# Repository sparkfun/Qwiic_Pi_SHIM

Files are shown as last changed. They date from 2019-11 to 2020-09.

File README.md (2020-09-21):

SparkFun Qwiic SHIM for Raspberry Pi
========================================

SparkFun Qwiic SHIM for Raspberry Pi

[*SparkFun Qwiic SHIM for Raspberry Pi (15794)*](https://www.sparkfun.com/products/15794)

A small breakout board to add a qwiic connector to your Raspberry Pi 40pin header. SHIM (Shove Hardware In the Middle).

Repository Contents
-------------------

* **/Hardware** - Eagle design files (.brd, .sch)

Documentation
--------------
* **[Hookup Guide](https://learn.sparkfun.com/tutorials/qwiic-shim-for-raspberry-pi-hookup-guide)** - Basic hookup guide for the SparkFun Qwiic SHIM for Raspberry Pi. 

License Information
-------------------

This product is _**open source**_! 

Please review the LICENSE.md file for license information. 

If you have any questions or concerns on licensing, please contact technical support on our [SparkFun forums](https://forum.sparkfun.com/viewforum.php?f=152).

Distributed as-is; no warranty is given.

- Your friends at SparkFun.

_<COLLABORATION CREDIT>_

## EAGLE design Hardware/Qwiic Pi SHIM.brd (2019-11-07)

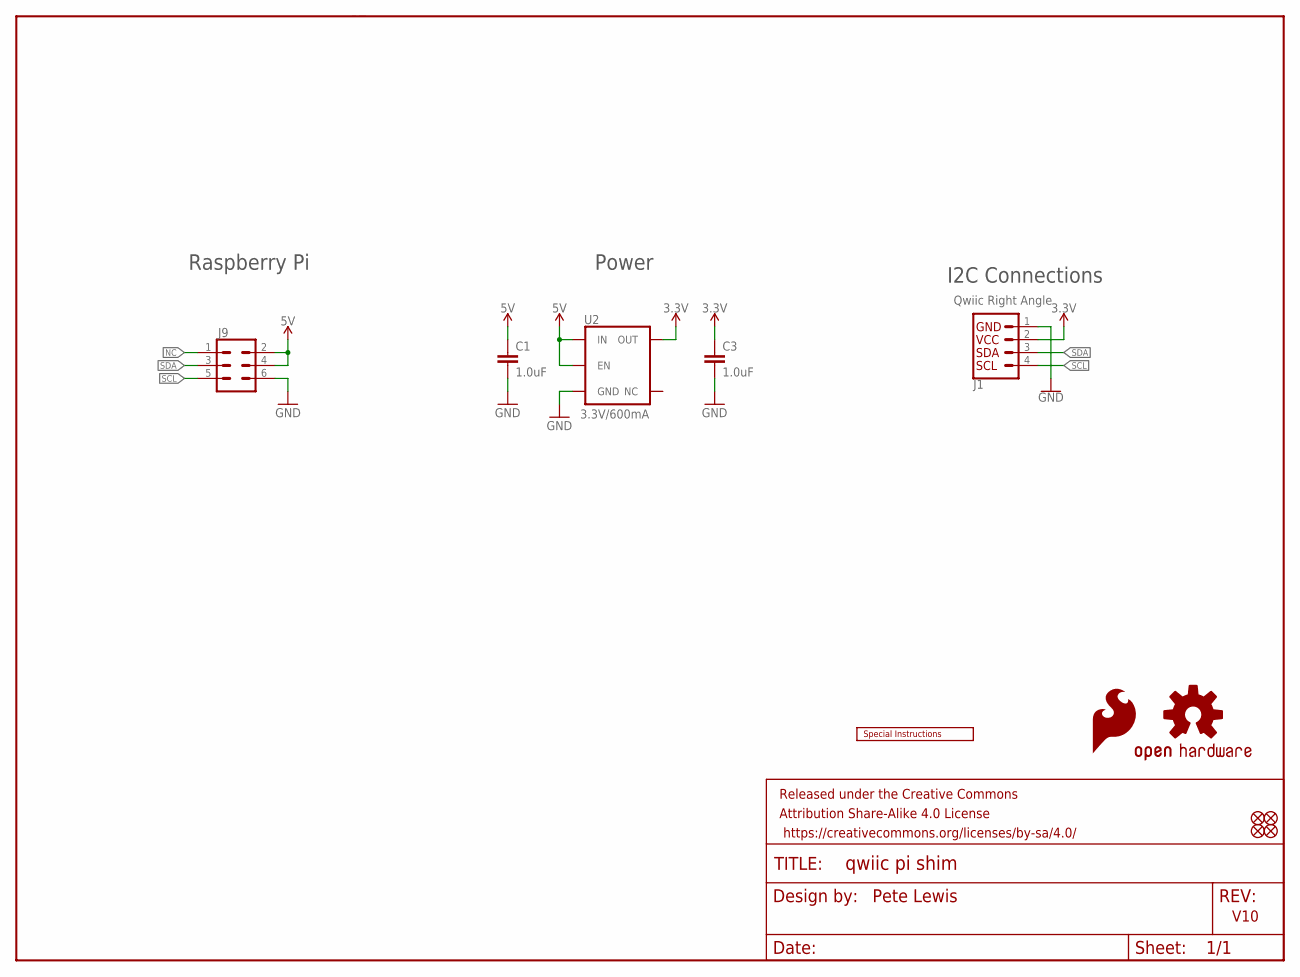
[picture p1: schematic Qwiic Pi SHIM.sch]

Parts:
C1, C3: 1.0uF; 0603
FD1, FD2, FD3, FD4: FIDUCIALUFIDUCIAL; FIDUCIAL-MICRO
FRAME1: FRAME-LETTER; CREATIVE_COMMONS
J1: Qwiic Right Angle; 1X04_1MM_RA
J9: SPARKFUN-CONNECTORS_CONN_03X2SINGLE_SLOT-4MILS; SPARKFUN-CONNECTORS_2X3-NS_PISHIM_LOCKING_SLOTS-4MILS
LOGO1: OSHW-LOGOMINI; OSHW-LOGO-MINI
U2: 3.3V/600mA; SOT23-5
U$1: SFE_LOGO_FLAME.1_INCH; SFE_LOGO_FLAME_.1
U$4: SPECIAL_INSTRUCTIONS-ORDERING; ORDERING_INSTRUCTIONS

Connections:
3.3V: C3.1, J1.2, U2.5 (OUT)
5V: C1.1, J9.2, J9.4, U2.1 (IN), U2.3 (EN)
GND: C1.2, C3.2, J1.1, J9.6, U2.2 (GND)
NC: J9.1
SCL: J1.4, J9.5
SDA: J1.3, J9.3

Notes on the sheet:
Pete Lewis
Raspberry Pi
V10
I2C Connections
Power

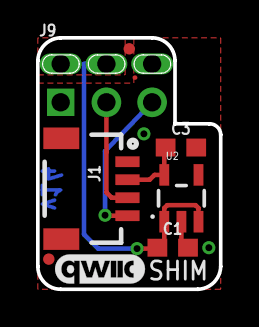
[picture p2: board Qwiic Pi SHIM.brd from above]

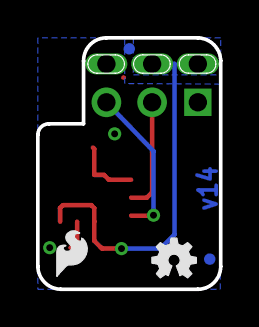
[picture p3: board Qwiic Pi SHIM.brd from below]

Board: 2 copper layers, 10.2 x 14.0 mm, 14 parts (4 on the bottom side), 5 nets.

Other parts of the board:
U$3: QWIIC_5MM

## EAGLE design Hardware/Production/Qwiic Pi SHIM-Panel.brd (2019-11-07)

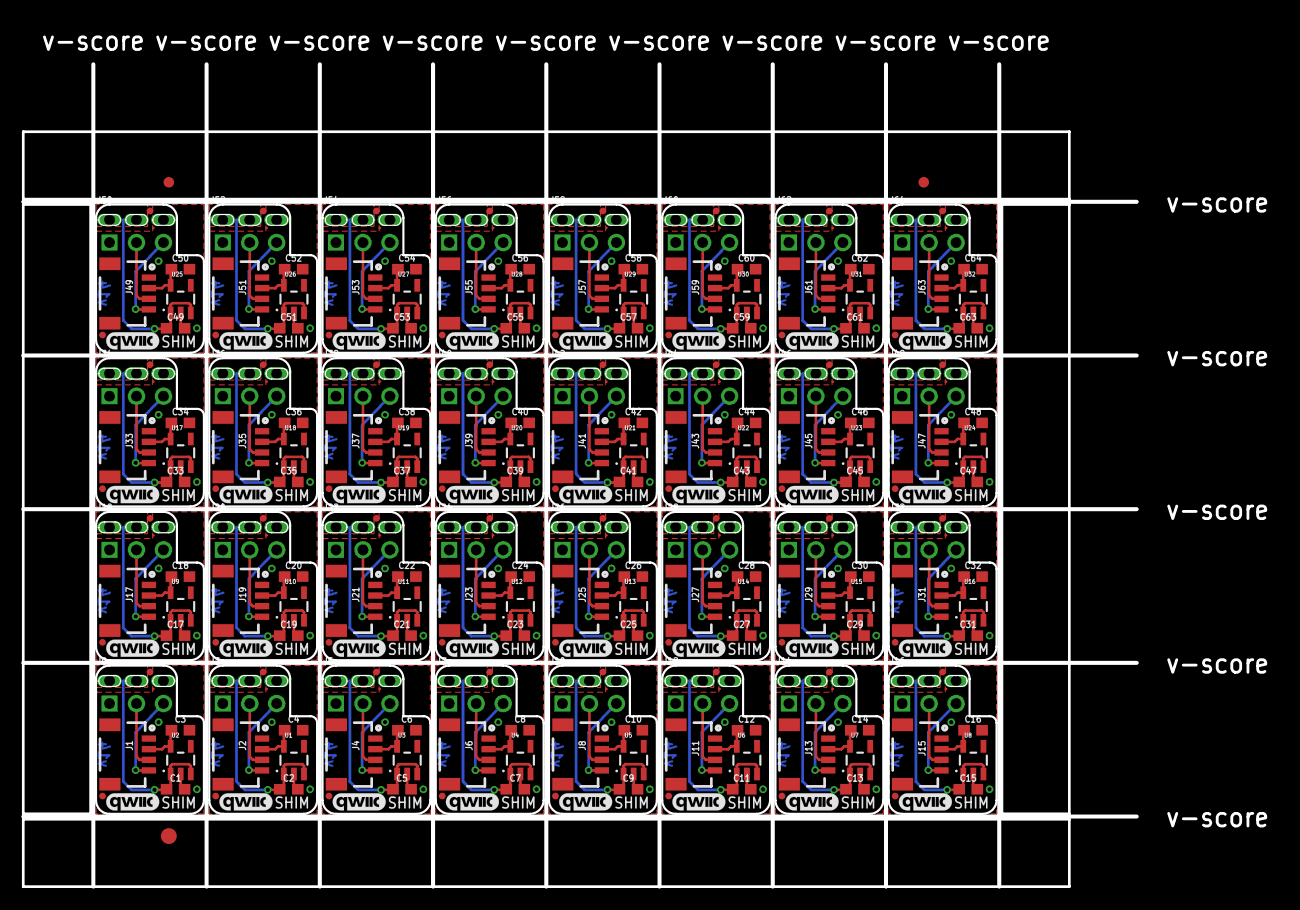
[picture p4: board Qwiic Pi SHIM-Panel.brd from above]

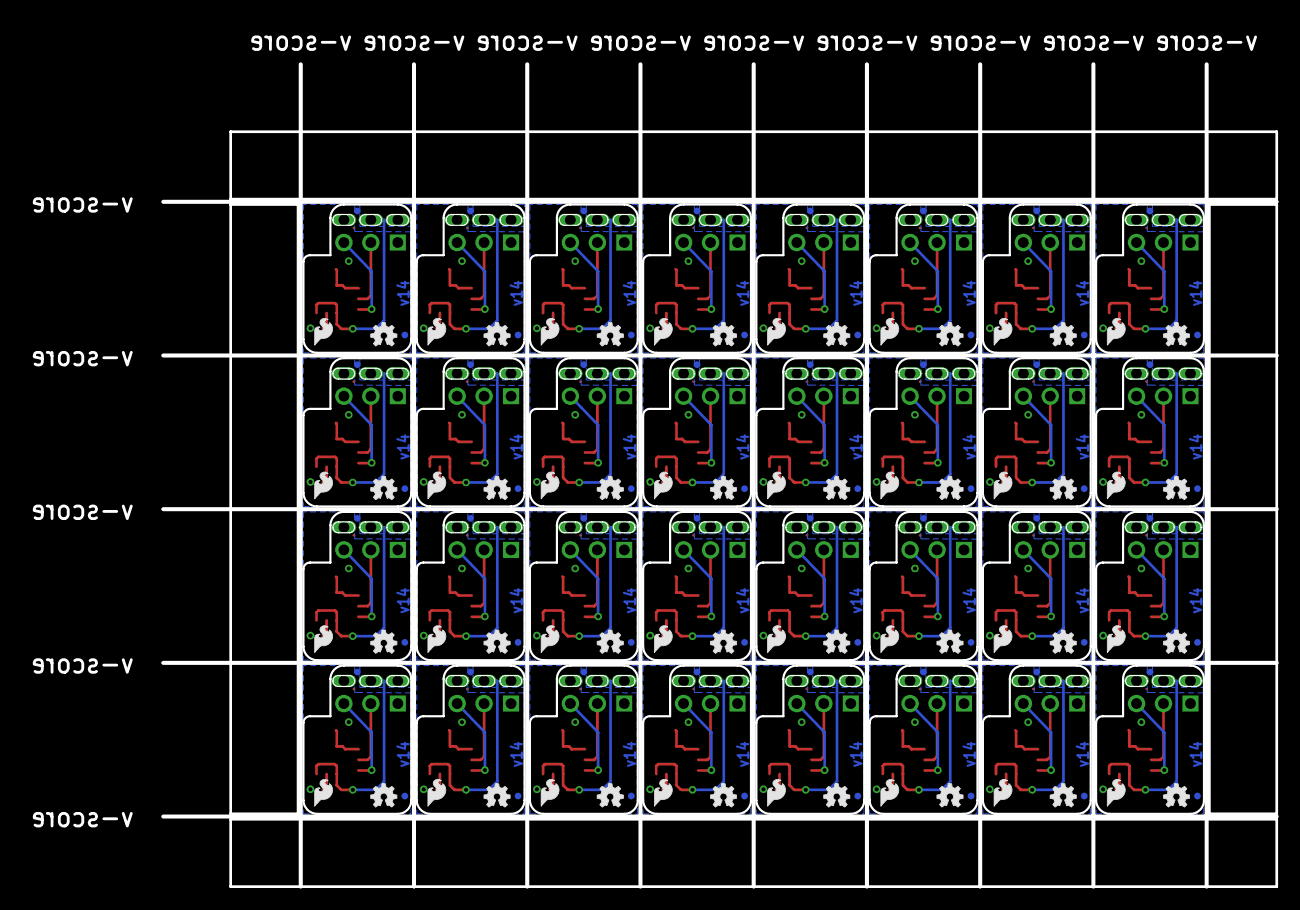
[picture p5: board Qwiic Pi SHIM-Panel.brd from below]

Board: 2 copper layers, 104.9 x 77.5 mm, 387 parts (128 on the bottom side), 160 nets.

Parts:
C1, C2, C3, C4, C5, C6, C7, C8, C9, C10, C11, C12, C13, C14, C15, C16, C17, C18, C19, C20, C21, C22, C23, C24, C25, C26, C27, C28, C29, C30, C31, C32, C33, C34, C35, C36, C37, C38, C39, C40, C41, C42, C43, C44, C45, C46, C47, C48, C49, C50, C51, C52, C53, C54, C55, C56, C57, C58, C59, C60, C61, C62, C63, C64: 1.0uF; 0603
E$1, E$2: FIDUCIAL-1X2
E$3: FIDUCIAL-1.5X3
FD1, FD2, FD3, FD4, FD5, FD6, FD7, FD8, FD9, FD10, FD11, FD12, FD13, FD14, FD15, FD16, FD17, FD18, FD19, FD20, FD21, FD22, FD23, FD24, FD25, FD26, FD27, FD28, FD29, FD30, FD31, FD32, FD33, FD34, FD35, FD36, FD37, FD38, FD39, FD40, FD41, FD42, FD43, FD44, FD45, FD46, FD47, FD48, FD49, FD50, FD51, FD52, FD53, FD54, FD55, FD56, FD57, FD58, FD59, FD60, FD61, FD62, FD63, FD64, FD65, FD66, FD67, FD68, FD69, FD70, FD71, FD72, FD73, FD74, FD75, FD76, FD77, FD78, FD79, FD80, FD81, FD82, FD83, FD84, FD85, FD86, FD87, FD88, FD89, FD90, FD91, FD92, FD93, FD94, FD95, FD96, FD97, FD98, FD99, FD100, FD101, FD102, FD103, FD104, FD105, FD106, FD107, FD108, FD109, FD110, FD111, FD112, FD113, FD114, FD115, FD116, FD117, FD118, FD119, FD120, FD121, FD122, FD123, FD124, FD125, FD126, FD127, FD128: FIDUCIALUFIDUCIAL; FIDUCIAL-MICRO
J1, J2, J4, J6, J8, J11, J13, J15, J17, J19, J21, J23, J25, J27, J29, J31, J33, J35, J37, J39, J41, J43, J45, J47, J49, J51, J53, J55, J57, J59, J61, J63: Qwiic Right Angle; 1X04_1MM_RA
J3, J5, J7, J9, J10, J12, J14, J16, J18, J20, J22, J24, J26, J28, J30, J32, J34, J36, J38, J40, J42, J44, J46, J48, J50, J52, J54, J56, J58, J60, J62, J64: SPARKFUN-CONNECTORS_2X3-NS_PISHIM_LOCKING_SLOTS-4MILS
LOGO1, LOGO2, LOGO3, LOGO4, LOGO5, LOGO6, LOGO7, LOGO8, LOGO9, LOGO10, LOGO11, LOGO12, LOGO13, LOGO14, LOGO15, LOGO16, LOGO17, LOGO18, LOGO19, LOGO20, LOGO21, LOGO22, LOGO23, LOGO24, LOGO25, LOGO26, LOGO27, LOGO28, LOGO29, LOGO30, LOGO31, LOGO32: OSHW-LOGOMINI; OSHW-LOGO-MINI
U1, U2, U3, U4, U5, U6, U7, U8, U9, U10, U11, U12, U13, U14, U15, U16, U17, U18, U19, U20, U21, U22, U23, U24, U25, U26, U27, U28, U29, U30, U31, U32: 3.3V/600mA; SOT23-5
U$1, U$2, U$5, U$7, U$9, U$11, U$13, U$15, U$17, U$19, U$21, U$23, U$25, U$27, U$29, U$31, U$33, U$35, U$37, U$39, U$41, U$43, U$45, U$47, U$49, U$51, U$53, U$55, U$57, U$59, U$61, U$63: SFE_LOGO_FLAME.1_INCH; SFE_LOGO_FLAME_.1
U$3, U$4, U$6, U$8, U$10, U$12, U$14, U$16, U$18, U$20, U$22, U$24, U$26, U$28, U$30, U$32, U$34, U$36, U$38, U$40, U$42, U$44, U$46, U$48, U$50, U$52, U$54, U$56, U$58, U$60, U$62, U$64: QWIIC_5MM

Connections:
3.3V: C3.1, J1.2, U2.5
3.3V1: C4.1, J2.2, U1.5
3.3V2: C6.1, J4.2, U3.5
3.3V3: C8.1, J6.2, U4.5
3.3V4: C10.1, J8.2, U5.5
3.3V5: C12.1, J11.2, U6.5
3.3V6: C14.1, J13.2, U7.5
3.3V7: C16.1, J15.2, U8.5
3.3V8: C18.1, J17.2, U9.5
3.3V9: C20.1, J19.2, U10.5
3.3V10: C22.1, J21.2, U11.5
3.3V11: C24.1, J23.2, U12.5
3.3V12: C26.1, J25.2, U13.5
3.3V13: C28.1, J27.2, U14.5
3.3V14: C30.1, J29.2, U15.5
3.3V15: C32.1, J31.2, U16.5
3.3V16: C34.1, J33.2, U17.5
3.3V17: C36.1, J35.2, U18.5
3.3V18: C38.1, J37.2, U19.5
3.3V19: C40.1, J39.2, U20.5
3.3V20: C42.1, J41.2, U21.5
3.3V21: C44.1, J43.2, U22.5
3.3V22: C46.1, J45.2, U23.5
3.3V23: C48.1, J47.2, U24.5
3.3V24: C50.1, J49.2, U25.5
3.3V25: C52.1, J51.2, U26.5
3.3V26: C54.1, J53.2, U27.5
3.3V27: C56.1, J55.2, U28.5
3.3V28: C58.1, J57.2, U29.5
3.3V29: C60.1, J59.2, U30.5
3.3V30: C62.1, J61.2, U31.5
3.3V31: C64.1, J63.2, U32.5
5V: C1.1, J9.2, J9.4, U2.1, U2.3
5V1: C2.1, J3.2, J3.4, U1.1, U1.3
5V2: C5.1, J5.2, J5.4, U3.1, U3.3
5V3: C7.1, J7.2, J7.4, U4.1, U4.3
5V4: C9.1, J10.2, J10.4, U5.1, U5.3
5V5: C11.1, J12.2, J12.4, U6.1, U6.3
5V6: C13.1, J14.2, J14.4, U7.1, U7.3
5V7: C15.1, J16.2, J16.4, U8.1, U8.3
5V8: C17.1, J18.2, J18.4, U9.1, U9.3
5V9: C19.1, J20.2, J20.4, U10.1, U10.3
5V10: C21.1, J22.2, J22.4, U11.1, U11.3
5V11: C23.1, J24.2, J24.4, U12.1, U12.3
5V12: C25.1, J26.2, J26.4, U13.1, U13.3
5V13: C27.1, J28.2, J28.4, U14.1, U14.3
5V14: C29.1, J30.2, J30.4, U15.1, U15.3
5V15: C31.1, J32.2, J32.4, U16.1, U16.3
5V16: C33.1, J34.2, J34.4, U17.1, U17.3
5V17: C35.1, J36.2, J36.4, U18.1, U18.3
5V18: C37.1, J38.2, J38.4, U19.1, U19.3
5V19: C39.1, J40.2, J40.4, U20.1, U20.3
5V20: C41.1, J42.2, J42.4, U21.1, U21.3
5V21: C43.1, J44.2, J44.4, U22.1, U22.3
5V22: C45.1, J46.2, J46.4, U23.1, U23.3
5V23: C47.1, J48.2, J48.4, U24.1, U24.3
5V24: C49.1, J50.2, J50.4, U25.1, U25.3
5V25: C51.1, J52.2, J52.4, U26.1, U26.3
5V26: C53.1, J54.2, J54.4, U27.1, U27.3
5V27: C55.1, J56.2, J56.4, U28.1, U28.3
5V28: C57.1, J58.2, J58.4, U29.1, U29.3
5V29: C59.1, J60.2, J60.4, U30.1, U30.3
5V30: C61.1, J62.2, J62.4, U31.1, U31.3
5V31: C63.1, J64.2, J64.4, U32.1, U32.3
GND: C1.2, C3.2, J1.1, J9.6, U2.2
GND1: C2.2, C4.2, J2.1, J3.6, U1.2
GND2: C5.2, C6.2, J4.1, J5.6, U3.2
GND3: C7.2, C8.2, J6.1, J7.6, U4.2
GND4: C9.2, C10.2, J8.1, J10.6, U5.2
GND5: C11.2, C12.2, J11.1, J12.6, U6.2
GND6: C13.2, C14.2, J13.1, J14.6, U7.2
GND7: C15.2, C16.2, J15.1, J16.6, U8.2
GND8: C17.2, C18.2, J17.1, J18.6, U9.2
GND9: C19.2, C20.2, J19.1, J20.6, U10.2
GND10: C21.2, C22.2, J21.1, J22.6, U11.2
GND11: C23.2, C24.2, J23.1, J24.6, U12.2
GND12: C25.2, C26.2, J25.1, J26.6, U13.2
GND13: C27.2, C28.2, J27.1, J28.6, U14.2
GND14: C29.2, C30.2, J29.1, J30.6, U15.2
GND15: C31.2, C32.2, J31.1, J32.6, U16.2
GND16: C33.2, C34.2, J33.1, J34.6, U17.2
GND17: C35.2, C36.2, J35.1, J36.6, U18.2
GND18: C37.2, C38.2, J37.1, J38.6, U19.2
GND19: C39.2, C40.2, J39.1, J40.6, U20.2
GND20: C41.2, C42.2, J41.1, J42.6, U21.2
GND21: C43.2, C44.2, J43.1, J44.6, U22.2
GND22: C45.2, C46.2, J45.1, J46.6, U23.2
GND23: C47.2, C48.2, J47.1, J48.6, U24.2
GND24: C49.2, C50.2, J49.1, J50.6, U25.2
GND25: C51.2, C52.2, J51.1, J52.6, U26.2
GND26: C53.2, C54.2, J53.1, J54.6, U27.2
GND27: C55.2, C56.2, J55.1, J56.6, U28.2
GND28: C57.2, C58.2, J57.1, J58.6, U29.2
GND29: C59.2, C60.2, J59.1, J60.6, U30.2
GND30: C61.2, C62.2, J61.1, J62.6, U31.2
GND31: C63.2, C64.2, J63.1, J64.6, U32.2
SCL: J1.4, J9.5
SCL1: J2.4, J3.5
SCL2: J4.4, J5.5
SCL3: J6.4, J7.5
SCL4: J8.4, J10.5
SCL5: J11.4, J12.5
SCL6: J13.4, J14.5
SCL7: J15.4, J16.5
SCL8: J17.4, J18.5
SCL9: J19.4, J20.5
SCL10: J21.4, J22.5
SCL11: J23.4, J24.5
SCL12: J25.4, J26.5
SCL13: J27.4, J28.5
SCL14: J29.4, J30.5
SCL15: J31.4, J32.5
SCL16: J33.4, J34.5
SCL17: J35.4, J36.5
SCL18: J37.4, J38.5
SCL19: J39.4, J40.5
SCL20: J41.4, J42.5
SCL21: J43.4, J44.5
SCL22: J45.4, J46.5
SCL23: J47.4, J48.5
SCL24: J49.4, J50.5
SCL25: J51.4, J52.5
SCL26: J53.4, J54.5
SCL27: J55.4, J56.5
SCL28: J57.4, J58.5
SCL29: J59.4, J60.5
SCL30: J61.4, J62.5
SCL31: J63.4, J64.5
SDA: J1.3, J9.3
SDA1: J2.3, J3.3
SDA2: J4.3, J5.3
SDA3: J6.3, J7.3
SDA4: J8.3, J10.3
SDA5: J11.3, J12.3
SDA6: J13.3, J14.3
SDA7: J15.3, J16.3
SDA8: J17.3, J18.3
SDA9: J19.3, J20.3
SDA10: J21.3, J22.3
SDA11: J23.3, J24.3
SDA12: J25.3, J26.3
SDA13: J27.3, J28.3
SDA14: J29.3, J30.3
SDA15: J31.3, J32.3
SDA16: J33.3, J34.3
SDA17: J35.3, J36.3
SDA18: J37.3, J38.3
SDA19: J39.3, J40.3
SDA20: J41.3, J42.3
SDA21: J43.3, J44.3
SDA22: J45.3, J46.3
SDA23: J47.3, J48.3
SDA24: J49.3, J50.3
SDA25: J51.3, J52.3
SDA26: J53.3, J54.3
SDA27: J55.3, J56.3
SDA28: J57.3, J58.3
SDA29: J59.3, J60.3
SDA30: J61.3, J62.3
SDA31: J63.3, J64.3

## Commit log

2019-10-03 Layout complete
    [Qwiic Pi SHIM.brd, Qwiic Pi SHIM.sch]
2019-10-03 fixed orientation so it goes over the pi
    added ordering instructions - 0.8mm thickness
    [Qwiic Pi SHIM.brd, Qwiic Pi SHIM.sch]
2019-10-22 Single slot version done
    [Qwiic Pi SHIM.brd, Qwiic Pi SHIM.sch]
2019-10-23 singel and double slot versions done
    [Qwiic Pi SHIM.brd, Qwiic Pi SHIM.sch, Qwiic Pi SHIM_double_slot.brd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]
2019-10-24 adjusted dimensions to match single to double
    -this lets a small amount of gnd pour around the corner.
    -moved fiductials
    -added gnd vias
    [Qwiic Pi SHIM.brd, Qwiic Pi SHIM_double_slot.brd]
2019-10-24 checklist run
    -approve DRC dimension errors, including wire stubbs for double connections on gnd and 5V
    [Qwiic Pi SHIM.brd, Qwiic Pi SHIM_double_slot.brd]
2019-10-28 Production files for both signel and double slot versions
    [Qwiic Pi SHIM-Panel.brd, Qwiic Pi SHIM_double_slot-Panel.brd]
2019-11-07 created footprints and variants for 2 mils and 4 mils tighter versions
2019-11-07 Created two more versions to test spacing
    2mil and 4mil spacing (tighter). At this point they are both not proven... PCBs inbound. I'm betting on the 4 mil.
    [Qwiic Pi SHIM_S2-Panel.brd, Qwiic Pi SHIM_S2.brd, Qwiic Pi SHIM_S2.sch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]
2019-11-18 2 mils tighter version wins - cleaning up repo
    -commiting to the 2 mils tighter version (single slot)
    -deleted all the other prototype versions
    -renamed files to product name (removing the "S2")
    [Qwiic Pi SHIM-Panel.brd, Qwiic Pi SHIM.brd, Qwiic Pi SHIM.sch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]
2020-09-30 Reverting to tighter spacing (aka v14 or "4MILS")
    -updated single brd files, panel files (and production gerbers)
    [Qwiic Pi SHIM-Panel.brd, Qwiic Pi SHIM.brd, Qwiic Pi SHIM.sch]

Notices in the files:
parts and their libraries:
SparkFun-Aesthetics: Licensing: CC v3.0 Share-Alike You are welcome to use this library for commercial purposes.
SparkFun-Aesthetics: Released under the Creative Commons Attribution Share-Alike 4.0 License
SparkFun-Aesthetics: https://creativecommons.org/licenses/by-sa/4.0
